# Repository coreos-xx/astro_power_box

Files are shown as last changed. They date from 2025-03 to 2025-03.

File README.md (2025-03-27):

# Astro Power Box 

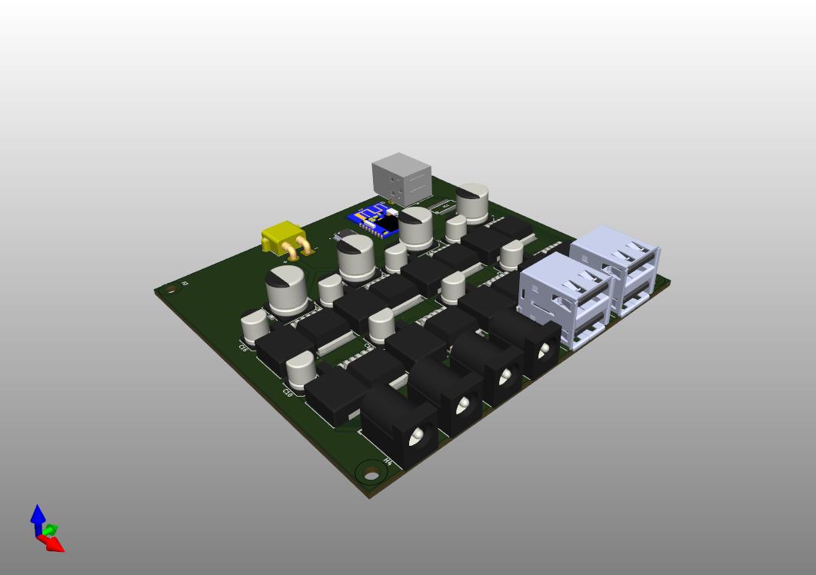
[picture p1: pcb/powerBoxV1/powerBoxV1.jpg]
[](./pcb/powerBoxV1/powerBoxV1.jpg)
## Overview

PBV1 Power Distribution Box is designed for **astrophotography setups**, allowing users to efficiently power and control their astronomical equipment. It provides multiple **USB and 12V outputs**, making it an essential component for **observatory automation** and **field setups**.

## Key Features

✅ 4 switchable **USB 2.0 ports** (3A max per port)\
✅ 4 switchable **12V output ports** (3A max per port)\
✅ Configurable **persistent boot states** for outputs\
✅ **ASCOM and INDI driver** support for remote control\
✅ **Bluetooth connectivity** for serial communication\
✅ Supports up to **150W of total power distribution**

## Technical Specifications

### **Electrical**

| Specification | Max | Typical | Min |
| --- | --- | --- | --- |
| Input Voltage (Vin) | 15V | 12V | 5V  |
| Power Consumption | 15A | - | - |
| USB2 Ports | 4 | - | - |
| 12V Outputs | 4 | - | - |

### **Physical**

| Specification | Value |
| --- | --- |
| Dimensions | 110 mm x 100 mm x 31 mm |
| Weight | 250 grams |
| Enclosure | Plastic (PLA thermoplastic) |
| Mounting | Pre-drilled holes |

### **Environmental Conditions**

| Condition | Range |
| --- | --- |
| Operating Temperature | -10°C to 50°C |
| Storage Temperature | -20°C to 60°C |
| Humidity Range | 10%-90% (non-condensing) |

## Directory Structure

```
astro_power_box/
├── cad/         # 3D enclosure design (STEP)
├── code/        # MCU firmware (Arduino)
├── doc/         # Documentation (LaTeX, images)
├── pcb/         # KiCad PCB design files
└── README.md    # Project overview
```

## Device Operation

The PBV1 allows individual control of **USB and 12V outputs** via **serial Bluetooth communication**. The outputs are managed through **dedicated ASCOM and INDI drivers**, enabling integration with astrophotography software like **KStars and N.I.N.A.**

### **Control Features**

- **Remote switch control** for USB and 12V outputs
- **Default power states** configurable via software
- **Real-time power monitoring** (if applicable)

## Setup Instructions

### **Windows Setup**

1. Connect the **12V XT30 connector** to PBV1.
2. Connect a **USB-A to USB-B cable** between the host computer and PBV1.
3. Ensure the computer is discoverable for **Bluetooth devices**.
4. In Windows **Bluetooth settings**, add a new device.
5. Select **HC-05** and enter **PIN: 1234**.
6. A new **Serial Port** will appear under **COM and LPT** in **Device Manager**.
7. Note the **Serial Port name (e.g., COM6)** for ASCOM driver setup in NINA.

### **ASCOM Driver Installation (Windows)**

1. Download the latest ASCOM driver: [Download Here](https://drive.google.com/drive/folders/1Y-2tLgOCcrt2SNI-Vw1phUzMPFCBjFHW?usp=drive_link)
2. Run the installer and follow on-screen instructions.
3. Open your **astrophotography software** and configure the driver.
4. Set the **Serial Bluetooth port** as shown in **Device Manager**.
5. Assign labels for outputs (default: Switch 1 to 8).

### **INDI Driver Installation (Linux/Mac)**

🚧 **Not Released Yet**

## **Setting Up Custom Boot Configuration for Outputs**

1. Download the **BT Serial Android app**: [Google Play Store](https://play.google.com/store/apps/details?id=de.kai_morich.serial_bluetooth_terminal)
2. Pair your phone with **PBV1 Bluetooth module (HC-05)**.
3. Connect to **BT Serial Terminal** (Baud rate: **9600**).
4. Send `eX` where `X = 0-7` to set default boot states.
5. The device confirms changes and requires a reboot.
6. If modifying multiple outputs, send multiple commands before rebooting.

## Wiring & Pinout Diagrams

📌 See `doc/figures/ConnectionDiagram.png` for the full wiring diagram.

## Troubleshooting & FAQs

- **Device not detected?** → Check drivers and connections.
- **Power issues?** → Verify fuse settings and power source.
- **USB ports not working?** → Try a different USB cable.

## License

📜 This project is licensed under the **MIT License**.

## Contributing

Contributions are welcome! Open an **issue** or submit a **pull request**.

---

🚀 **PBV1 - Power Distribution Box for Astrophotography**

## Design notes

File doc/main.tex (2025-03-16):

\documentclass[a4paper,10pt,twocolumn]{article}
\usepackage{graphicx}
\usepackage{hyperref}
\usepackage{geometry}
\usepackage{titlesec}
\usepackage{fancyhdr}
\geometry{margin=1in}

% Define header and footer
\pagestyle{fancy}
\fancyhead[L]{\textbf{PBV1 Power Distribution Box}}
\fancyhead[R]{\today}
\fancyfoot[C]{\thepage}

\title{\textbf{Power Distribution Box for Astrophotography}\\\large Model: PBV1}
\author{Manufacturer: CoreOS}
\date{\today}

\begin{document}
\maketitle

\section*{Introduction}
\textbf{PBV1 Power Distribution Box} is designed for astrophotography setups, allowing users to efficiently power and control their astronomical equipment. It features both USB and 12V power outputs, making it an essential component for observatory automation and field setups.

\begin{center}
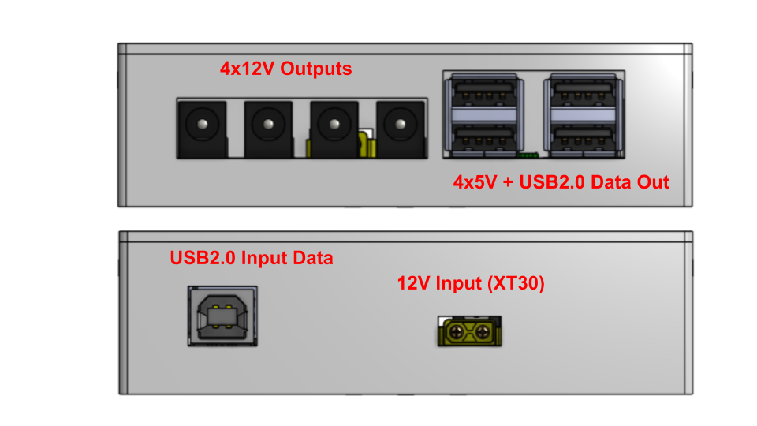
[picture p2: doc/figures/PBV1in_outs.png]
    % Add image of the device
   \caption{Inputs and outputs legend }
\end{center}

\subsection*{Key Features}
\begin{itemize}
    \item 4 switchable USB 2.0 ports (3A max per port).
    \item 4 switchable 12V output ports (3A max per port).
    \item Configurable persistent output boot states .
    \item ASCOM and INDI driver support for remote control.
    \item Up to 150W of total power distribution
\end{itemize}

\section*{Technical Specifications}
\subsection*{Electrical Specifications}
\begin{table}[h]
    \centering
    \begin{tabular}{|l|l|l|l|}
    \hline
    \textbf{Specification} & Max & Typical & Min \\
    \hline
    Input Voltage (Vin) & 15V & 12V & 5V \\
    Power Consumption & 15A & - & - \\
    USB2 Ports & 4 & - & - \\
    12V Outputs & 4 & - & - \\
    \hline
    \end{tabular}
    \caption{Electrical Specifications}
\end{table}

\subsection*{Physical Specifications}
\begin{table}[h]
    \centering
    \begin{tabular}{|l|l|}
    \hline
    \textbf{Specification} & \textbf{Value} \\
    \hline
    Dimensions & 110 mm x 100 mm x 31 mm \\
    Weight & 250 grams \\
    Enclosure & Plastic (PLA thermoplastic) \\
    Mounting & Pre-drilled holes \\
    \hline
    \end{tabular}
    \caption{Physical Specifications}
\end{table}

\subsection*{Environmental Conditions}
\begin{table}[h]
    \centering
    \begin{tabular}{|l|l|}
    \hline
    \textbf{Condition} & \textbf{Range} \\
    \hline
    Operating Temperature & -10 C to 50 C \\
    Storage Temperature & -20 C to 60\ C \\
    Humidity Range & 10\%-90\% (non-condensing) \\
    \hline
    \end{tabular}
    \caption{Environmental Conditions}
\end{table}

\section*{Device Operation}
The PBV1 allows individual control of connected devices via USB and 12V outputs through serial Bluetooth communication. The outputs are managed through dedicated ASCOM and INDI (not yet released) drivers, enabling integration with astrophotography software like KStars and N.I.N.A.

\subsection*{Control Features}
\begin{itemize}
    \item Remote switch control for USB and 12V outputs.
    \item Default power states configurable via software.
    \item Real-time power monitoring (if applicable).
\end{itemize}

\section*{Setting Up PBV1 (Windows)}
\begin{enumerate}
    \item Connect the 12V XT30 connector to the PBV1.
    \item Connect a USB-A to USB-B cable between the host computer and PBV1.
    \item Ensure the computer is discoverable for Bluetooth devices.
    \item In Windows Bluetooth settings, add a new Bluetooth device.
    \item Select HC-05 and enter PIN: 1234.
    \item A new Serial Port will appear under COM and LPT in Device Manager.
    \item Note the Serial Port name (e.g., COM6) for ASCOM driver setup in NINA.
\end{enumerate}

\section*{Driver and Software Installation}
\subsection*{ASCOM Driver Installation (Windows)}
\begin{enumerate}
    \item Download the latest ASCOM driver from \url{https://drive.google.com/drive/folders/1Y-2tLgOCcrt2SNI-Vw1phUzMPFCBjFHW?usp=drive_link}.
    \item Run the installer and follow the on-screen instructions.
    \item Open astrophotography software and configure the driver by pressing the settings/options button.
    \item In the options menu, set the Serial Bluetooth port as it appears in Device Manager during PBV1 setup.
    \item You can then specify a custom label (name) for each output. The default names are Switch 1 to 8.
\end{enumerate}

\subsection*{INDI Driver Installation (Linux/Mac) (Not Released Yet)}
\begin{enumerate}
    \item Ensure INDI is installed: `sudo apt install indi-full`
    \item Start INDI and connect the device in Ekos.
\end{enumerate}

\section*{Setting Up a Custom Boot Configuration for Outputs}
\begin{enumerate}
    \item Download the BT Serial Android app from \url{https://play.google.com/store/apps/details?id=de.kai_morich.serial_bluetooth_terminal&pcampaignid=web_share} or use a desktop serial terminal (e.g., Putty).
    \item Pair your phone to the BT device and connect via a serial terminal. On a PC/laptop, connect to the BT serial port using a terminal (Baud rate: 9600).
    \item To change the boot state of a specific output, send `eX`, where `X` is 0–7 specifying the desired output port.
    \item The device will confirm that the default boot state of the specified port has changed and prompt a reboot.
    \item If changing multiple outputs, repeat step 3, then reboot the device by unplugging the power.
\end{enumerate}

\section*{Wiring \& Pinout Diagrams}
The connection diagram shown below is an example of a practical use of the PBV1 power box. 
\begin{center}
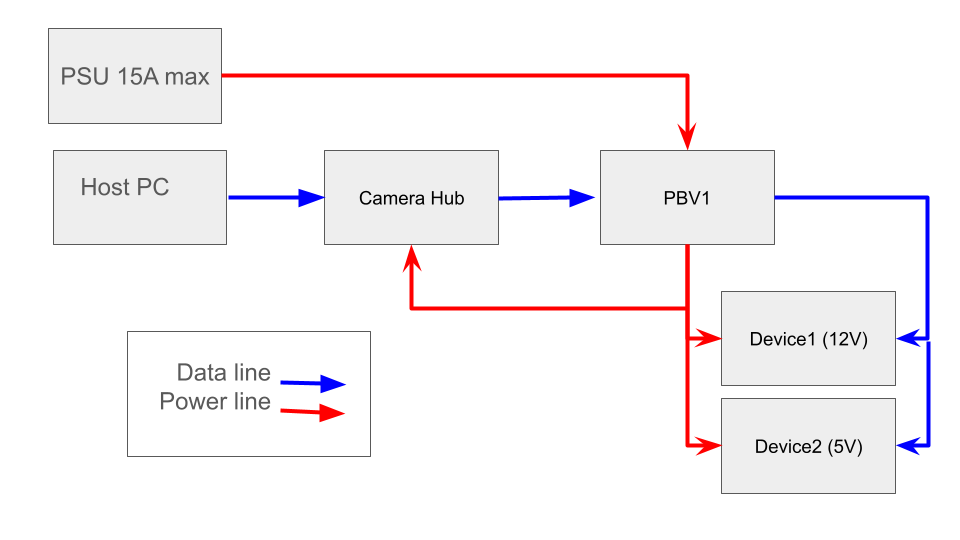
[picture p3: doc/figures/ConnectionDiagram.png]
    % Add wiring diagram
   \caption{Wiring diagram example}
\end{center}

\section*{Troubleshooting \& FAQs}
\textbf{Common Issues and Solutions}
\begin{itemize}
    \item \textbf{Device not detected:} Check drivers and connections.
    \item \textbf{Power output issues:} Verify fuse configuration and power source.
    \item \textbf{USB ports not working:} Try a different USB cable or check driver logs.
\end{itemize}

\section*{Warranty \& Support}
\begin{itemize}
    \item \textbf{Warranty:} There is absolutely no warranty for this device. The owner assumes full responsibility for any damage it may cause to other equipment.
    \item \textbf{Technical Support:} Limited support is provided. For critical issues, please contact \href{mailto:gcoreos@gmail.com}{this email}. Response times may vary significantly based on availability.
    \item \textbf{Knowledge page:} \url{https://drive.google.com/drive/folders/1Y-2tLgOCcrt2SNI-Vw1phUzMPFCBjFHW?usp=drive_link}.
\end{itemize}
\section*{Revision History}
\begin{table}[h]
    \centering
    \begin{tabular}{|c|c|c|}
    \hline
    Version & Date & Changes \\
    \hline
    1.0 & \today & Initial release \\
    \hline
    \end{tabular}
    \caption{Revision History}
\end{table}

\end{document}

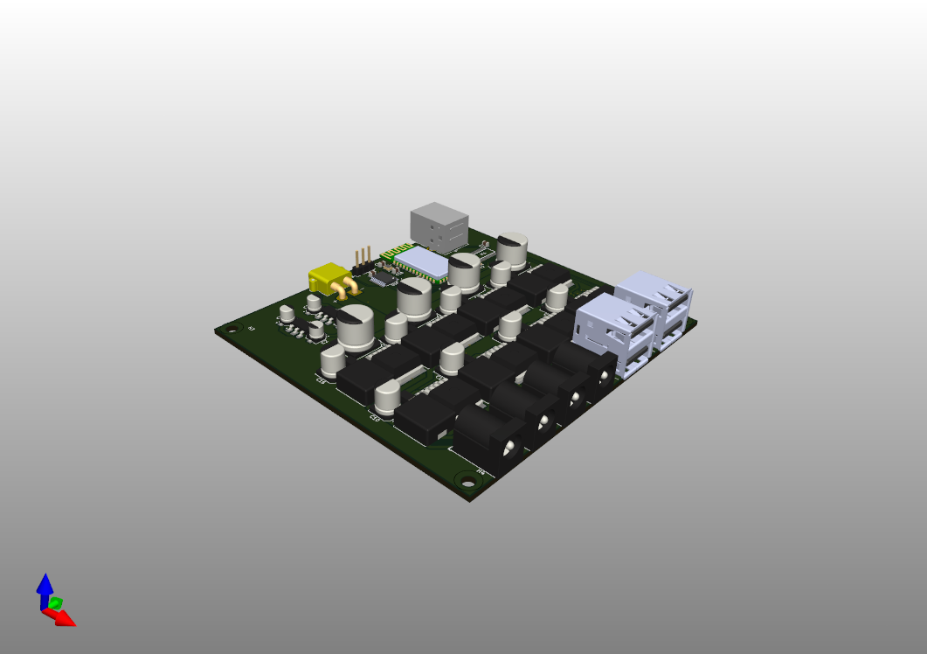
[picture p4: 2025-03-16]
pcb/powerBoxV1/powerBoxV1.png

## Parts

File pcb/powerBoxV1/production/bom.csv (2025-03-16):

Designator | Footprint | Quantity | Value | LCSC Part #
C1, C10, C12, C14, C16, C4, C6, C8 | CP_Elec_6.3x7.7 | 8 | 220uF
C11, C13, C17, C3 | 0805 | 4 | 100nF
C15, C5, C7, C9 | CP_Elec_10x10.5 | 4 | 680uF
C18, C19 | 0805 | 2 | 27p
C20 | CP_Elec_4x4.5 | 1 | 22uF
C21 | CP_Elec_4x4.5 | 1 | 10uF
C23, C24 | 0805 | 2 | 20p
D1, D2, D3, D4, D5, D6, D7, D8 | D_SMA | 8 | 5A, 40V Schottky Rectifier, IN5825
F1, F2, F3, F4 | 1812 | 4 | Polyfuse
F5, F6, F7, F8 | 2920 | 4 | Polyfuse
IC1 | FE1.1S_SSOP-28 | 1 | FE1.1S
J1 | AMASS_XT30PW-M_1x02_P2.50mm_Horizontal | 1 | XT30PW-M
J10, J7, J8, J9 | BarrelJack_Horizontal | 4 | Barrel_Jack_Switch
J12, J3 | USB_A_CUI_UJ2-ADH-TH_Horizontal_Stacked | 2 | USB_A_Stacked
J2 | USB_B_OST_USB-B1HSxx_Horizontal | 1 | USB_B
J4 | PinHeader_1x03_P2.54mm_Vertical | 1 | Conn_01x03_Pin
L1, L2, L3, L4, L5, L6, L7, L8 | L_10.4x10.4_H4.8 | 8 | 33uH
R1 | 0805 | 1 | 2.7k
U1 | SOT-223-3_TabPin2 | 1 | AMS1117-3.3
U10 | SOP65P640X121-20N | 1 | CH32V003F4P6
U12 | XCVR_HC-05 | 1 | HC-05
U2, U3, U4, U5 | TO-263-5_TabPin3 | 4 | LM2596S-5
U6, U7, U8, U9 | TO-263-5_TabPin3 | 4 | LM2596S-12
Y1, Y2 | Crystal_SMD_2520-4Pin_2.5x2.0mm | 2 | Crystal

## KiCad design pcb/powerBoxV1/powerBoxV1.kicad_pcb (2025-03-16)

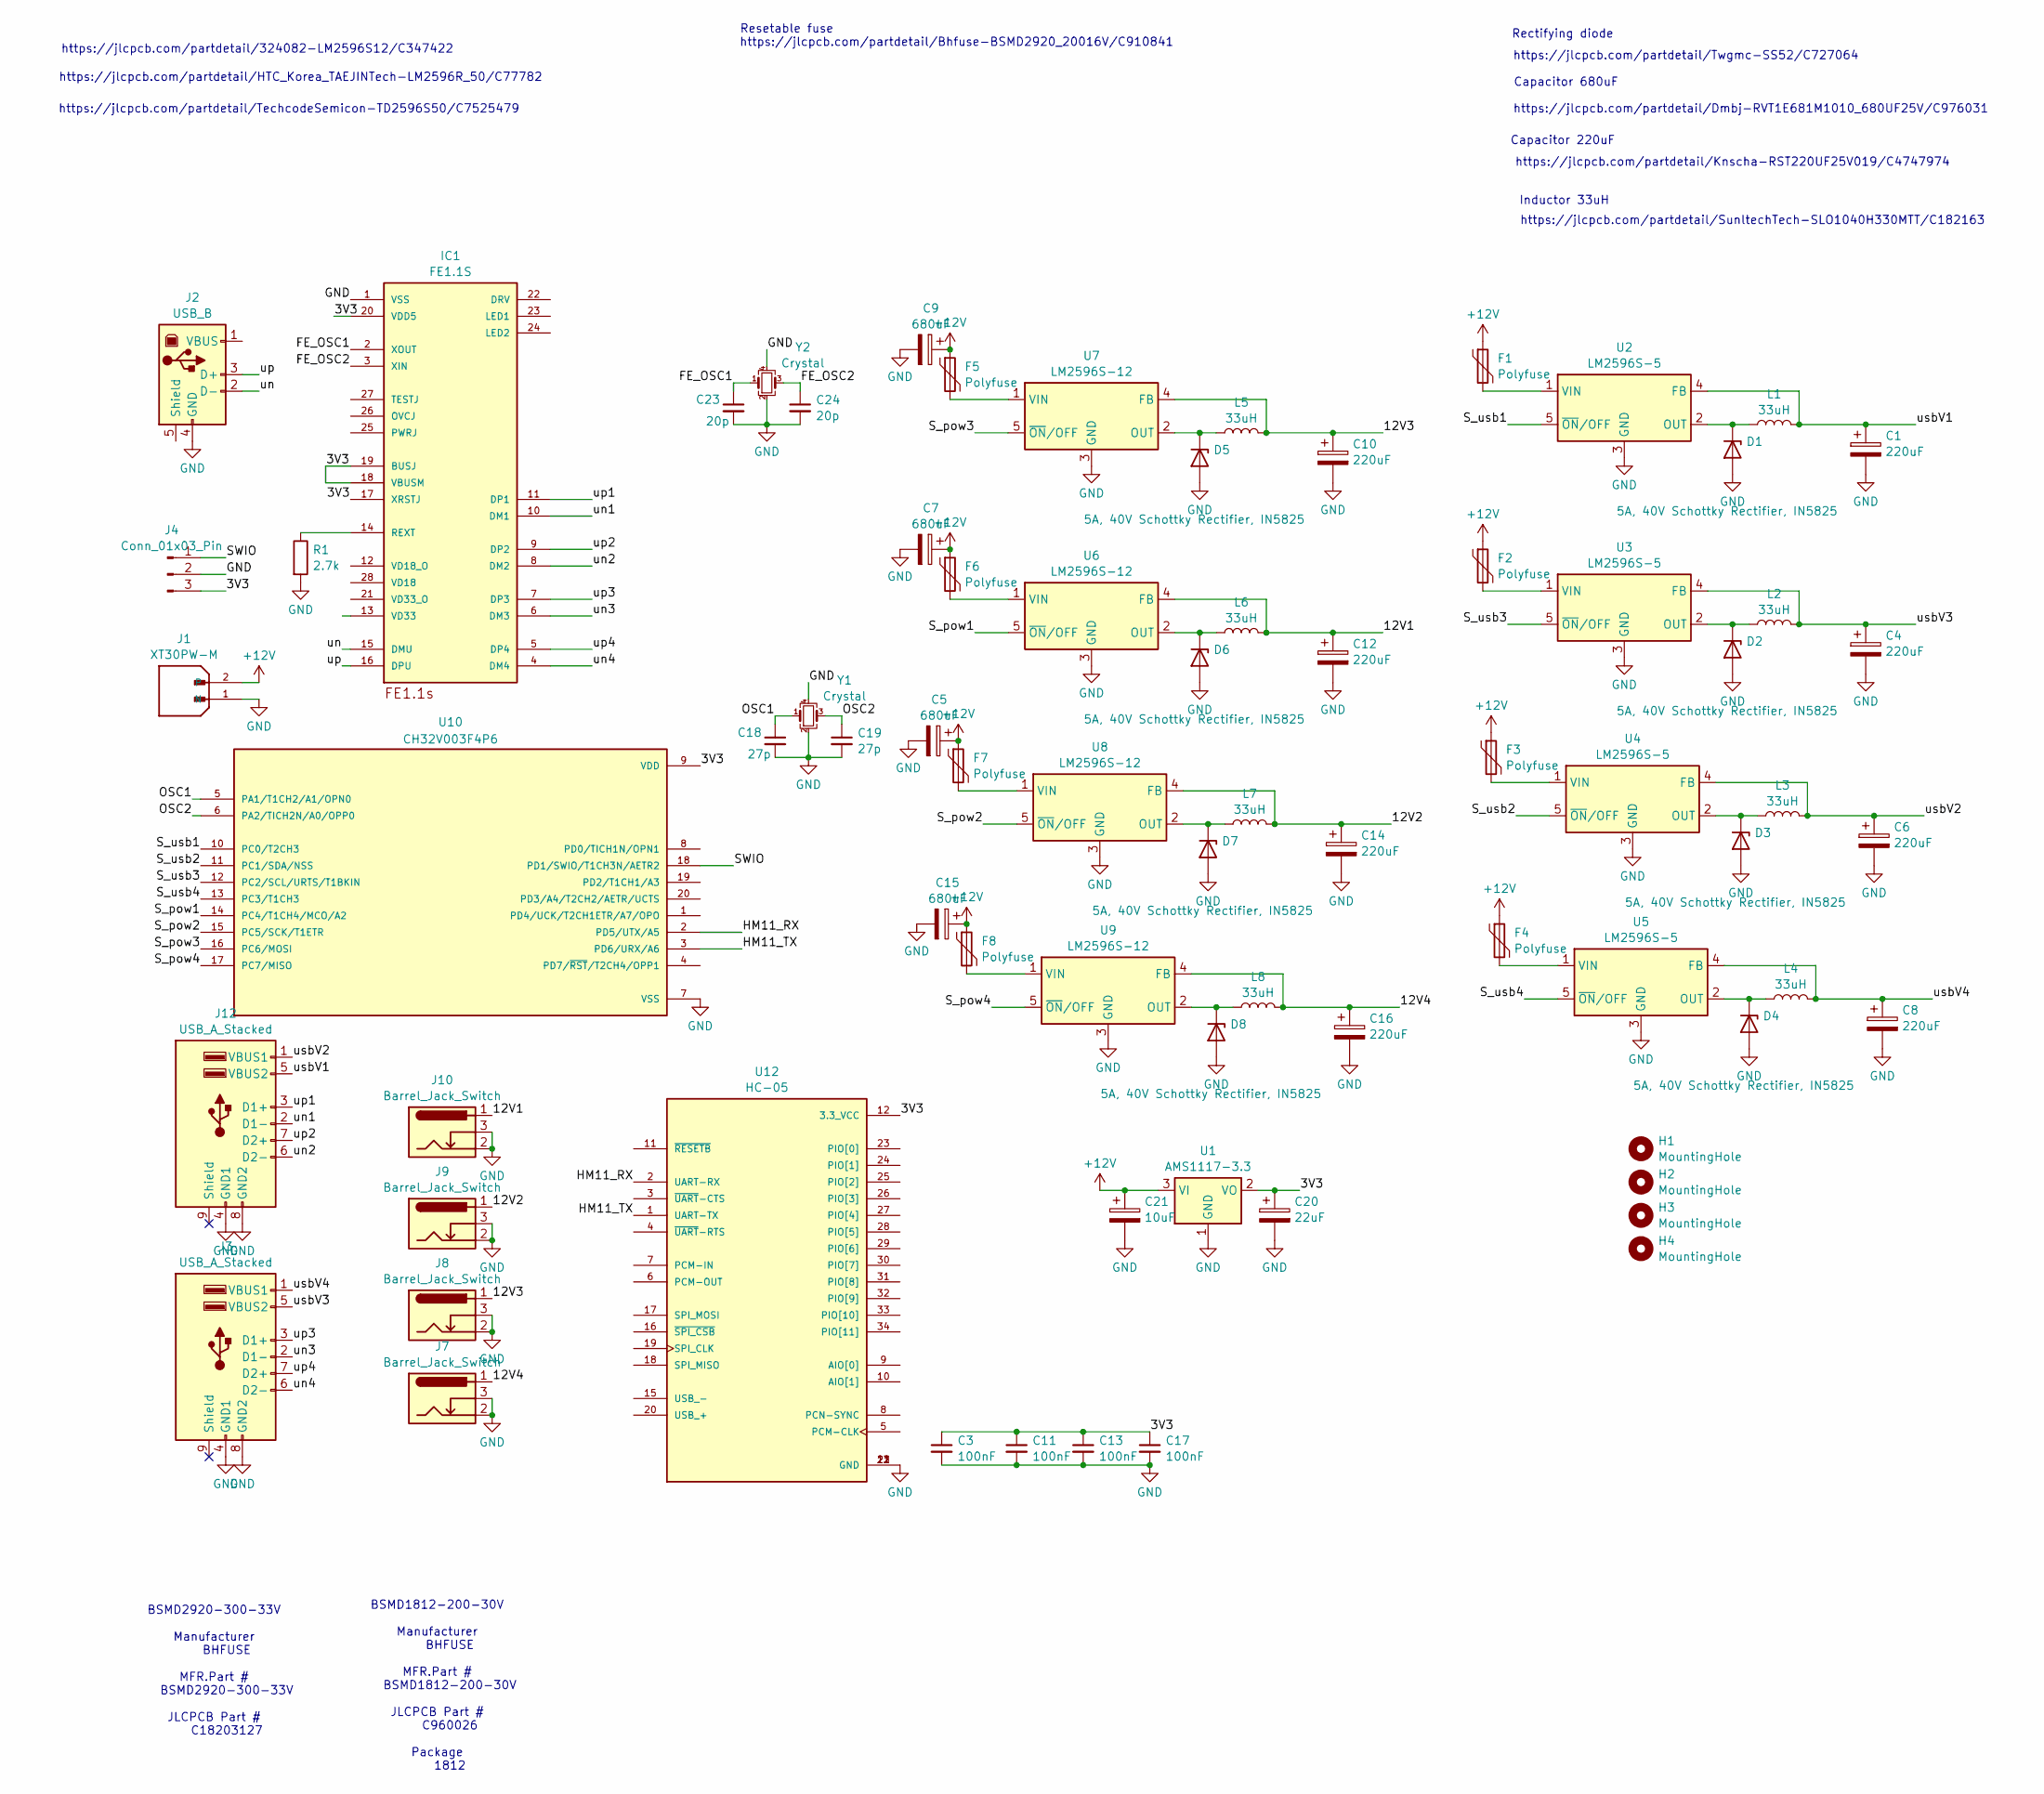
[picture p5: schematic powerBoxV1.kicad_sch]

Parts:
C1, C4, C6, C8, C10, C12, C14, C16: 220uF; CP_Elec_6.3x7.7
C3, C11, C13, C17: 100nF; C_0805_2012Metric
C5, C7, C9, C15: 680uF; CP_Elec_10x10.5
C18, C19: 27p; C_0805_2012Metric
C20: 22uF; CP_Elec_4x4.5
C21: 10uF; CP_Elec_4x4.5
C23, C24: 20p; C_0805_2012Metric
D1, D2, D3, D4, D5, D6, D7, D8: 5A, 40V Schottky Rectifier, IN5825; D_SMA
F1, F2, F3, F4: Polyfuse; Fuse_1812_4532Metric
F5, F6, F7, F8: Polyfuse; Fuse_2920_7451Metric
H1, H2, H3, H4: MountingHole; MountingHole_3.2mm_M3
IC1: FE1.1S; FE1.1S_SSOP-28
J1: XT30PW-M; AMASS_XT30PW-M_1x02_P2.50mm_Horizontal; PARTREV 1.2
J2: USB_B; USB_B_OST_USB-B1HSxx_Horizontal
J3, J12: USB_A_Stacked; USB_A_CUI_UJ2-ADH-TH_Horizontal_Stacked
J4: Conn_01x03_Pin; PinHeader_1x03_P2.54mm_Vertical
J7, J8, J9, J10: Barrel_Jack_Switch; BarrelJack_Horizontal
L1, L2, L3, L4, L5, L6, L7, L8: 33uH; L_10.4x10.4_H4.8
R1: 2.7k; R_0805_2012Metric
U1: AMS1117-3.3; SOT-223-3_TabPin2
U2, U3, U4, U5: LM2596S-5; TO-263-5_TabPin3
U6, U7, U8, U9: LM2596S-12; TO-263-5_TabPin3
U10: CH32V003F4P6; SOP65P640X121-20N; PARTREV 1.4
U12: HC-05; XCVR_HC-05; PARTREV v1.0
Y1, Y2: Crystal; Crystal_SMD_2520-4Pin_2.5x2.0mm

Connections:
+12V: C5.1, C7.1, C9.1, C15.1, C21.1, F1.1, F2.1, F3.1, F4.1, F5.1, F6.1, F7.1, F8.1, J1.2, U1.3 (VI)
/3V3: C3.1, C11.1, C13.1, C17.1, C20.1, IC1.17 (XRSTJ), IC1.18 (VBUSM), IC1.19 (BUSJ), IC1.20 (VDD5), J4.3, U1.2 (VO), U10.9 (VDD), U12.12 (3.3_VCC)
/12V1: C12.1, J10.1, L6.2, U6.4 (FB)
/12V2: C14.1, J9.1, L7.2, U8.4 (FB)
/12V3: C10.1, J8.1, L5.2, U7.4 (FB)
/12V4: C16.1, J7.1, L8.2, U9.4 (FB)
/FE_OSC1: C23.1, IC1.2 (XOUT), Y2.1
/FE_OSC2: C24.1, IC1.3 (XIN), Y2.3
/HM11_RX: U10.2 (PD5/UTX/A5), U12.2 (UART-RX)
/HM11_TX: U10.3 (PD6/URX/A6), U12.1 (UART-TX)
/OSC1: C18.1, U10.5 (PA1/T1CH2/A1/OPN0), Y1.1
/OSC2: C19.1, U10.6 (PA2/TICH2N/A0/OPP0), Y1.3
/SWIO: J4.1, U10.18 (PD1/SWIO/T1CH3N/AETR2)
/S_pow1: U6.5 (~ON/OFF), U10.14 (PC4/T1CH4/MCO/A2)
/S_pow2: U8.5 (~ON/OFF), U10.15 (PC5/SCK/T1ETR)
/S_pow3: U7.5 (~ON/OFF), U10.16 (PC6/MOSI)
/S_pow4: U9.5 (~ON/OFF), U10.17 (PC7/MISO)
/S_usb1: U2.5 (~ON/OFF), U10.10 (PC0/T2CH3)
/S_usb2: U4.5 (~ON/OFF), U10.11 (PC1/SDA/NSS)
/S_usb3: U3.5 (~ON/OFF), U10.12 (PC2/SCL/URTS/T1BKIN)
/S_usb4: U5.5 (~ON/OFF), U10.13 (PC3/T1CH3)
/un: IC1.15 (DMU), J2.2 (D-)
/un1: IC1.10 (DM1), J12.2 (D1-)
/un2: IC1.8 (DM2), J12.6 (D2-)
/un3: IC1.6 (DM3), J3.2 (D1-)
/un4: IC1.4 (DM4), J3.6 (D2-)
/up: IC1.16 (DPU), J2.3 (D+)
/up1: IC1.11 (DP1), J12.3 (D1+)
/up2: IC1.9 (DP2), J12.7 (D2+)
/up3: IC1.7 (DP3), J3.3 (D1+)
/up4: IC1.5 (DP4), J3.7 (D2+)
/usbV1: C1.1, J12.5 (VBUS2), L1.2, U2.4 (FB)
/usbV2: C6.1, J12.1 (VBUS1), L3.2, U4.4 (FB)
/usbV3: C4.1, J3.5 (VBUS2), L2.2, U3.4 (FB)
/usbV4: C8.1, J3.1 (VBUS1), L4.2, U5.4 (FB)
GND: C1.2, C3.2, C4.2, C5.2, C6.2, C7.2, C8.2, C9.2, C10.2, C11.2, C12.2, C13.2, C14.2, C15.2, C16.2, C17.2, C18.2, C19.2, C20.2, C21.2, C23.2, C24.2, D1.2 (A), D2.2 (A), D3.2 (A), D4.2 (A), D5.2 (A), D6.2 (A), D7.2 (A), D8.2 (A), IC1.1 (VSS), J1.1 (N), J2.4 (GND), J3.4 (GND1), J3.8 (GND2), J4.2, J7.2, J7.3, J8.2, J8.3, J9.2, J9.3, J10.2, J10.3, J12.4 (GND1), J12.8 (GND2), R1.2, U1.1 (GND), U2.3 (GND), U3.3 (GND), U4.3 (GND), U5.3 (GND), U6.3 (GND), U7.3 (GND), U8.3 (GND), U9.3 (GND), U10.7 (VSS), U12.13 (GND), U12.21 (GND), U12.22 (GND), Y1.2, Y1.4, Y2.2, Y2.4
unnamed: D1.1 (K), L1.1, U2.2 (OUT)
unnamed: D2.1 (K), L2.1, U3.2 (OUT)
unnamed: D3.1 (K), L3.1, U4.2 (OUT)
unnamed: D4.1 (K), L4.1, U5.2 (OUT)
unnamed: D5.1 (K), L5.1, U7.2 (OUT)
unnamed: D6.1 (K), L6.1, U6.2 (OUT)
unnamed: D7.1 (K), L7.1, U8.2 (OUT)
unnamed: D8.1 (K), L8.1, U9.2 (OUT)
unnamed: IC1.14 (REXT), R1.1
unnamed: F1.2, U2.1 (VIN)
unnamed: F2.2, U3.1 (VIN)
unnamed: F3.2, U4.1 (VIN)
unnamed: F4.2, U5.1 (VIN)
unnamed: F6.2, U6.1 (VIN)
unnamed: F5.2, U7.1 (VIN)
unnamed: F7.2, U8.1 (VIN)
unnamed: F8.2, U9.1 (VIN)

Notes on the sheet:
Inductor 33uH
https://jlcpcb.com/partdetail/Knscha-RST220UF25V019/C4747974
https://jlcpcb.com/partdetail/Bhfuse-BSMD2920_20016V/C910841
https://jlcpcb.com/partdetail/SunltechTech-SLO1040H330MTT/C182163
Capacitor 680uF
BSMD2920-300-33V Manufacturer BHFUSE MFR.Part # BSMD2920-300-33V JLCPCB Part # C18203127
BSMD1812-200-30V Manufacturer BHFUSE MFR.Part # BSMD1812-200-30V JLCPCB Part # C960026 Package 1812
https://jlcpcb.com/partdetail/Twgmc-SS52/C727064
https://jlcpcb.com/partdetail/324082-LM2596S12/C347422
https://jlcpcb.com/partdetail/HTC_Korea_TAEJINTech-LM2596R_50/C77782
https://jlcpcb.com/partdetail/Dmbj-RVT1E681M1010_680UF25V/C976031
Rectifying diode
https://jlcpcb.com/partdetail/TechcodeSemicon-TD2596S50/C7525479
Capacitor 220uF
Resetable fuse

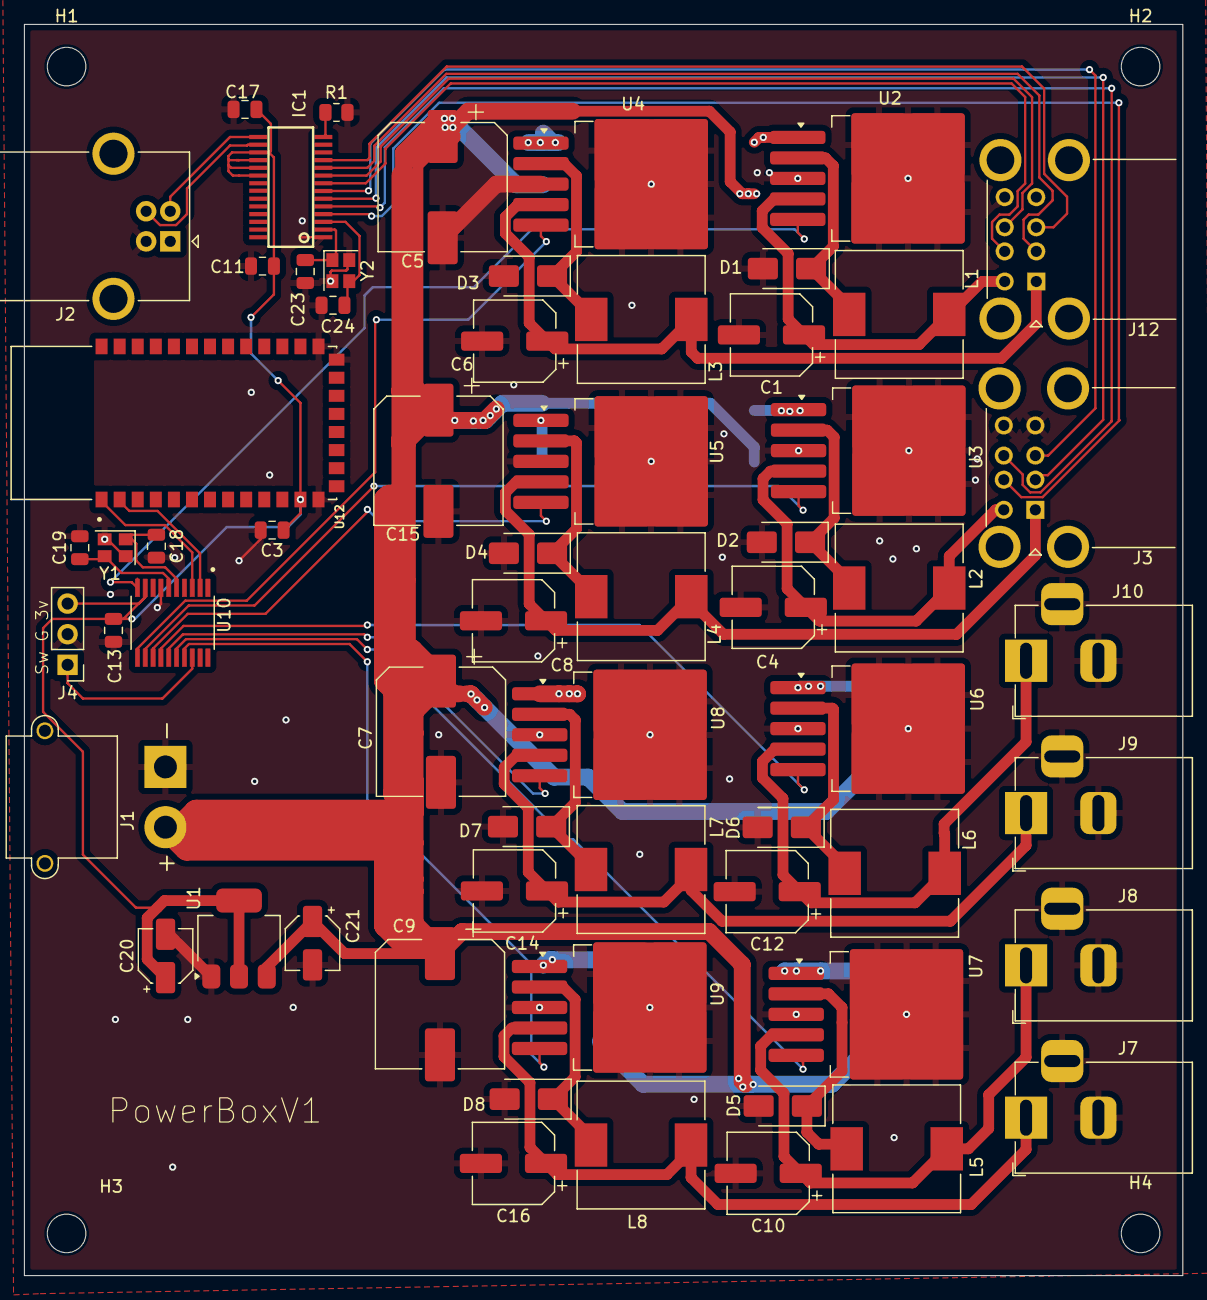
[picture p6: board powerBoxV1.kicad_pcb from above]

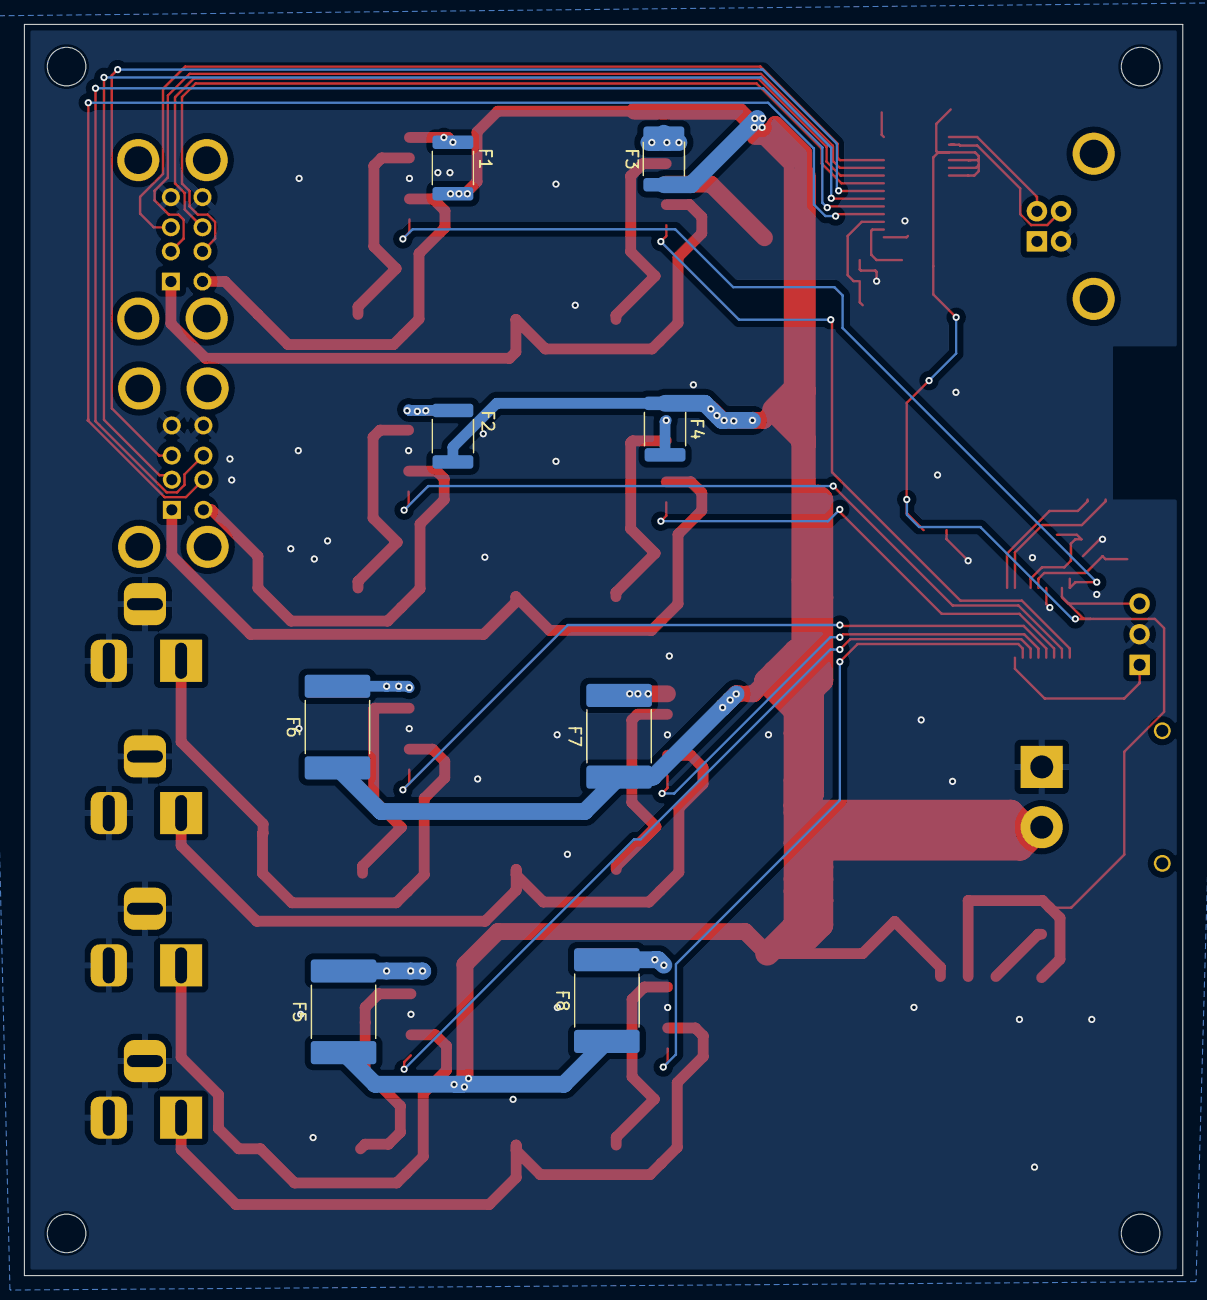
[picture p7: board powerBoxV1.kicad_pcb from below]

Board: 2 copper layers, 96.1 x 103.8 mm, 74 parts (8 on the bottom side), 53 nets.

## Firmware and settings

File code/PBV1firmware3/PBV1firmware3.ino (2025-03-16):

mmun#include <EEPROM.h>

#define OUT0 PC0
#define OUT1 PC1
#define OUT2 PC2
#define OUT3 PC3
#define OUT4 PC4
#define OUT5 PC5
#define OUT6 PC6
#define OUT7 PC7

#define EEPROM_MAGIC_BYTE 0x15  // A marker to check if EEPROM is initialized
#define EEPROM_ADDR_MAGIC 0      // EEPROM Address for magic byte
#define EEPROM_ADDR_STATES 1      // EEPROM Address where pin states start

int outArray[8] = {OUT0, OUT1, OUT2, OUT3, OUT4, OUT5, OUT6, OUT7};
boolean stateArray[8] = { LOW, LOW, LOW, LOW, LOW, LOW, LOW, LOW}; // Default states

void loadStateFromEEPROM() {
    EEPROM.begin(); // Initialize EEPROM

    byte magicByte = EEPROM.read(EEPROM_ADDR_MAGIC);
    if (magicByte == EEPROM_MAGIC_BYTE) {
        //Serial.println("Loading stored configuration...");
        for (int i = 0; i < 8; i++) {
            stateArray[i] = EEPROM.read(EEPROM_ADDR_STATES + i);
        }
    } else {
        //Serial.println("No valid config found. Using defaults.");
        saveStateToEEPROM();  // Save default states to EEPROM
    }
}

void saveStateToEEPROM() {
    EEPROM.begin();

    Serial.println("Saving configuration to EEPROM...");

    EEPROM.write(EEPROM_ADDR_MAGIC, EEPROM_MAGIC_BYTE);  // Write magic byte
    for (int i = 0; i < 8; i++) {
        EEPROM.write(EEPROM_ADDR_STATES + i, stateArray[i]);
    }
    EEPROM.commit();  // Save changes

    Serial.println("Configuration saved. Reboot required.");
}

void setup() {
    Serial.begin(9600);
    delay(1000);

    //Serial.println("CH32V003 EEPROM Debug Start");

    loadStateFromEEPROM();  // Load saved configuration or use default

    for (int i = 0; i < 8; i++) {
        pinMode(outArray[i], OUTPUT);
        digitalWrite(outArray[i], stateArray[i]);  // Apply stored states
    }
}

void loop() {
    if (Serial.available()) {
        char in = Serial.read(); // Read the first command character

        if (in == 's') {
            Serial.println(" ");
            int val = Serial.read();
            val = val - 48; // Convert ASCII to integer
            if (val >= 0 && val < 8) {
                stateArray[val] = !stateArray[val]; // Toggle state
                digitalWrite(outArray[val], stateArray[val]); // Update hardware
                Serial.println(!stateArray[val]); // Send new state
            } else {
                Serial.print("Invalid switch index ");
                Serial.println(val);
            }
        } else if (in == 'g') {
            Serial.println(" ");
            int val = Serial.read();
            val = val - 48;
            if (val >= 0 && val < 8) {
                Serial.println(!stateArray[val]); // Send current state
            } else {
                Serial.print("Invalid switch index ");
                Serial.println(val);
            }
        } else if (in == 'e') {
            Serial.println(" ");
            int val = Serial.read();
            val = val - 48;
            if (val >= 0 && val < 8) {
                stateArray[val] = !stateArray[val]; // Toggle stored boot state
                saveStateToEEPROM();  // Save new boot state to EEPROM
                Serial.println("Boot state updated. Reboot required.");
            } else {
                Serial.print("Invalid switch index ");
                Serial.println(val);
            }
        } else {
            Serial.flush(); // Clear invalid input
        }
    }
}
